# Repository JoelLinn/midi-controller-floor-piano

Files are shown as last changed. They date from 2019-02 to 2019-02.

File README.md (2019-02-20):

# midi-controller-floor-piano
Converts your awful sounding floor piano into a midi keyboard controller you can hook up to your synthesizers.
It uses an ARM NXP LPC1113 MCU which is hopelessly overpowered but still quite cheap.

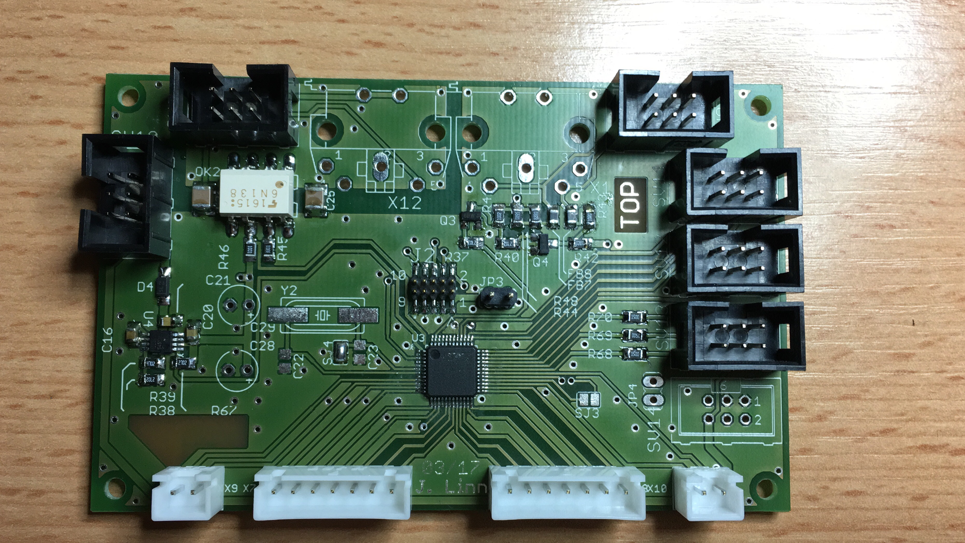
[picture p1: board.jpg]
Image of midi controller board

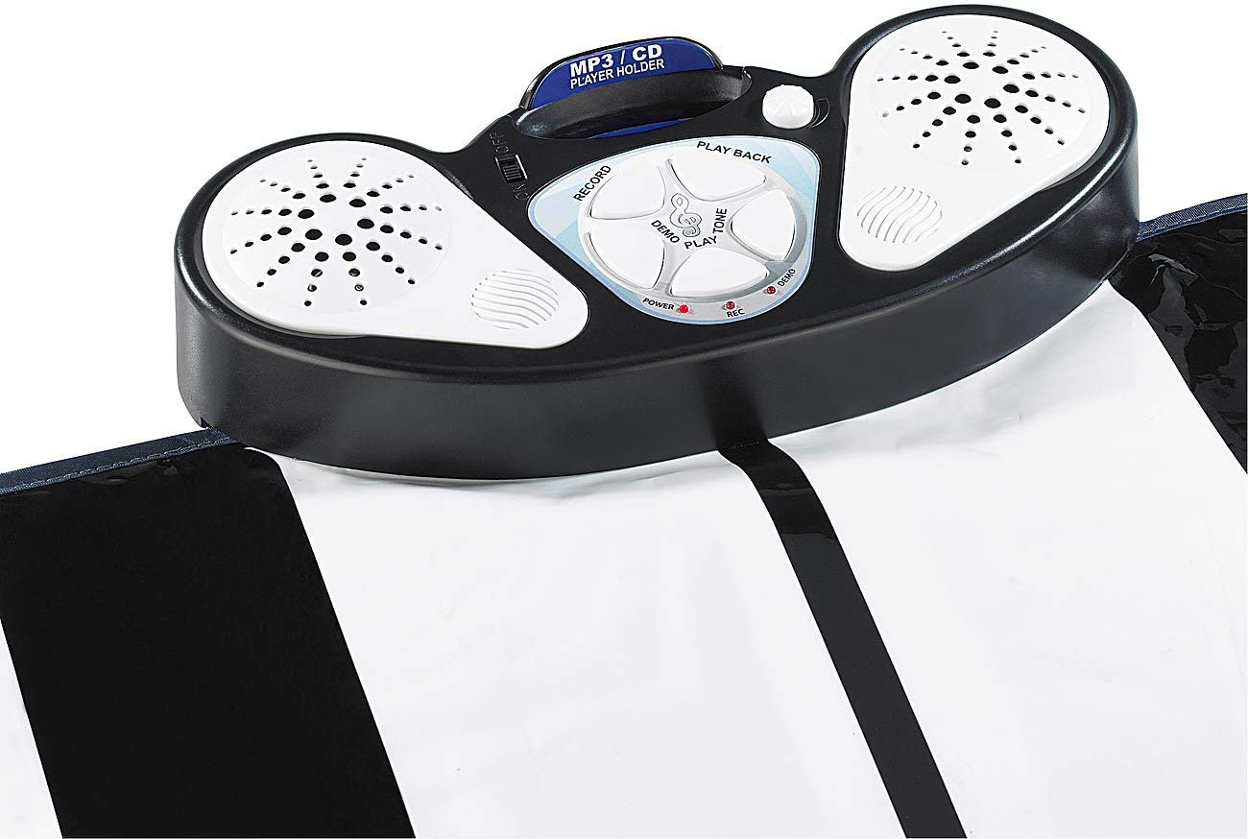
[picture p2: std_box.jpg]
Image of standard controller box


Fits where the stock board belonged and supports the original battery, buttons and leds.
The firmware, although working great, is merely in a POC state so I would prefer to hand it out only on request.

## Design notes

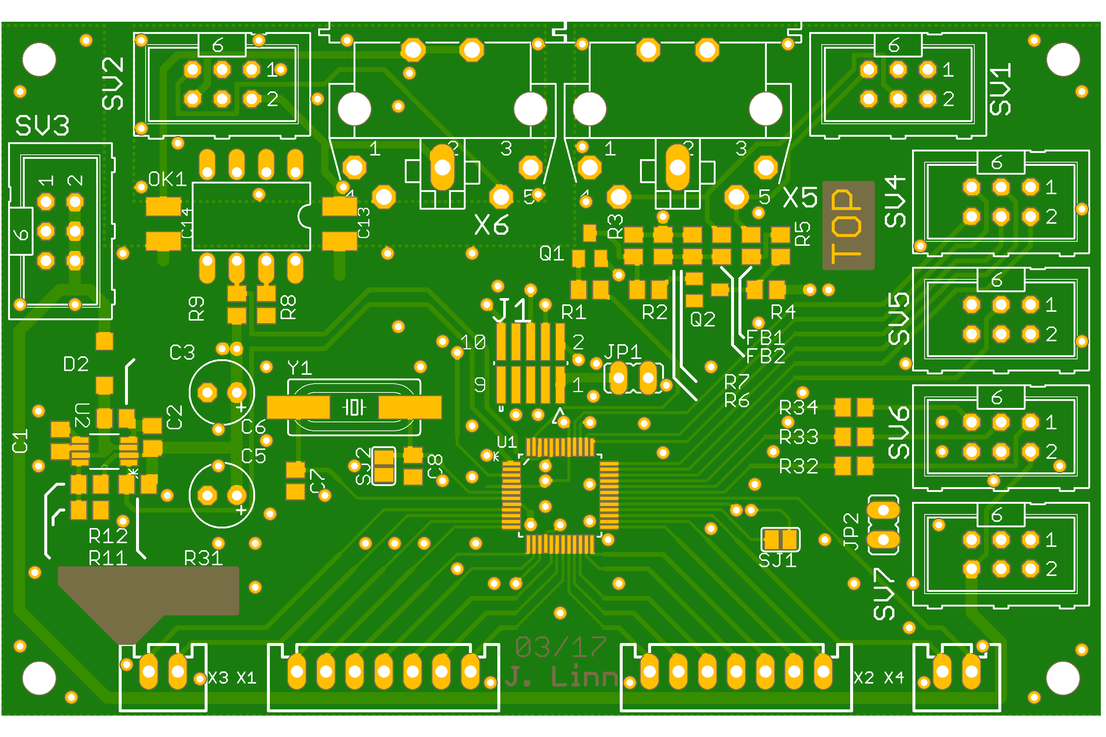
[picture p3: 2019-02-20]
board_top.png

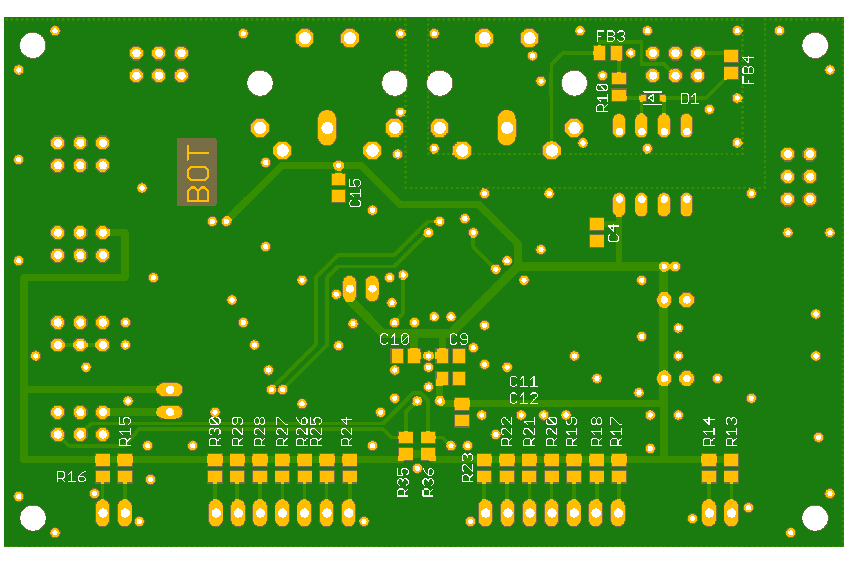
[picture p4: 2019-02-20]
board_bot.png

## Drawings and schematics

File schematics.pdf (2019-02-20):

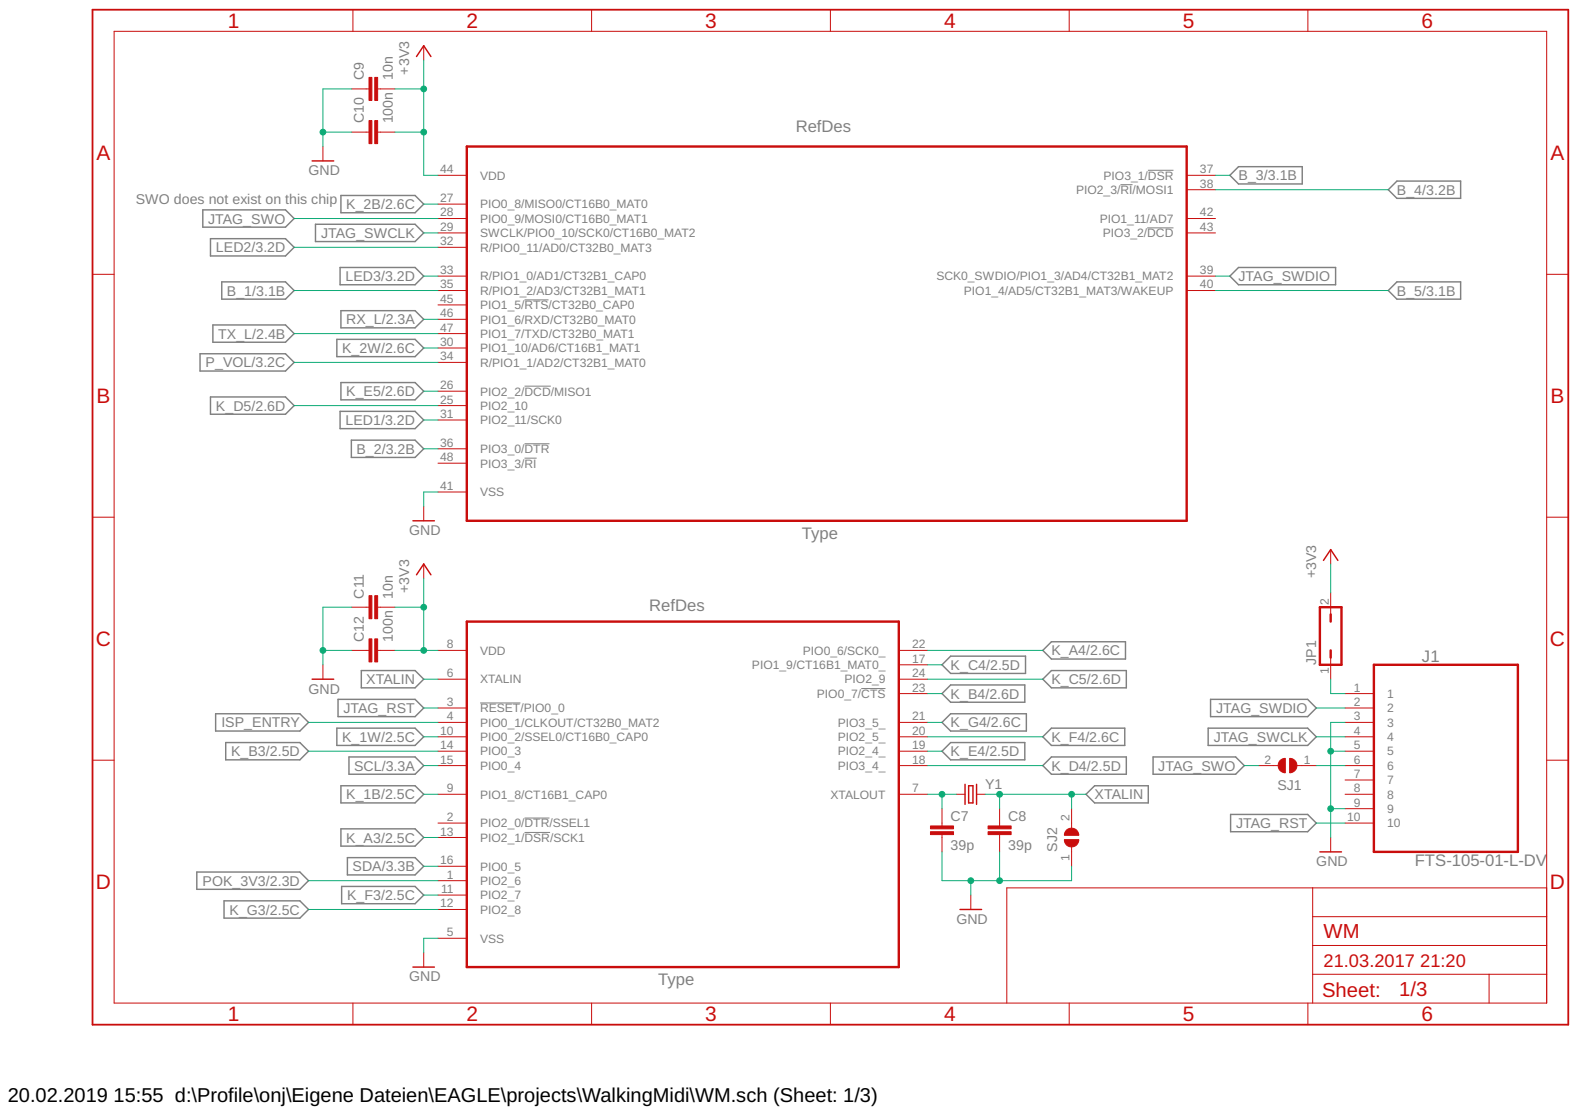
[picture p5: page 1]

SWO does not exist on this chip

20.02.2019 15:55 d:\Profile\onj\Eigene Dateien\EAGLE\projects\WalkingMidi\WM.sch (Sheet: 1/3)

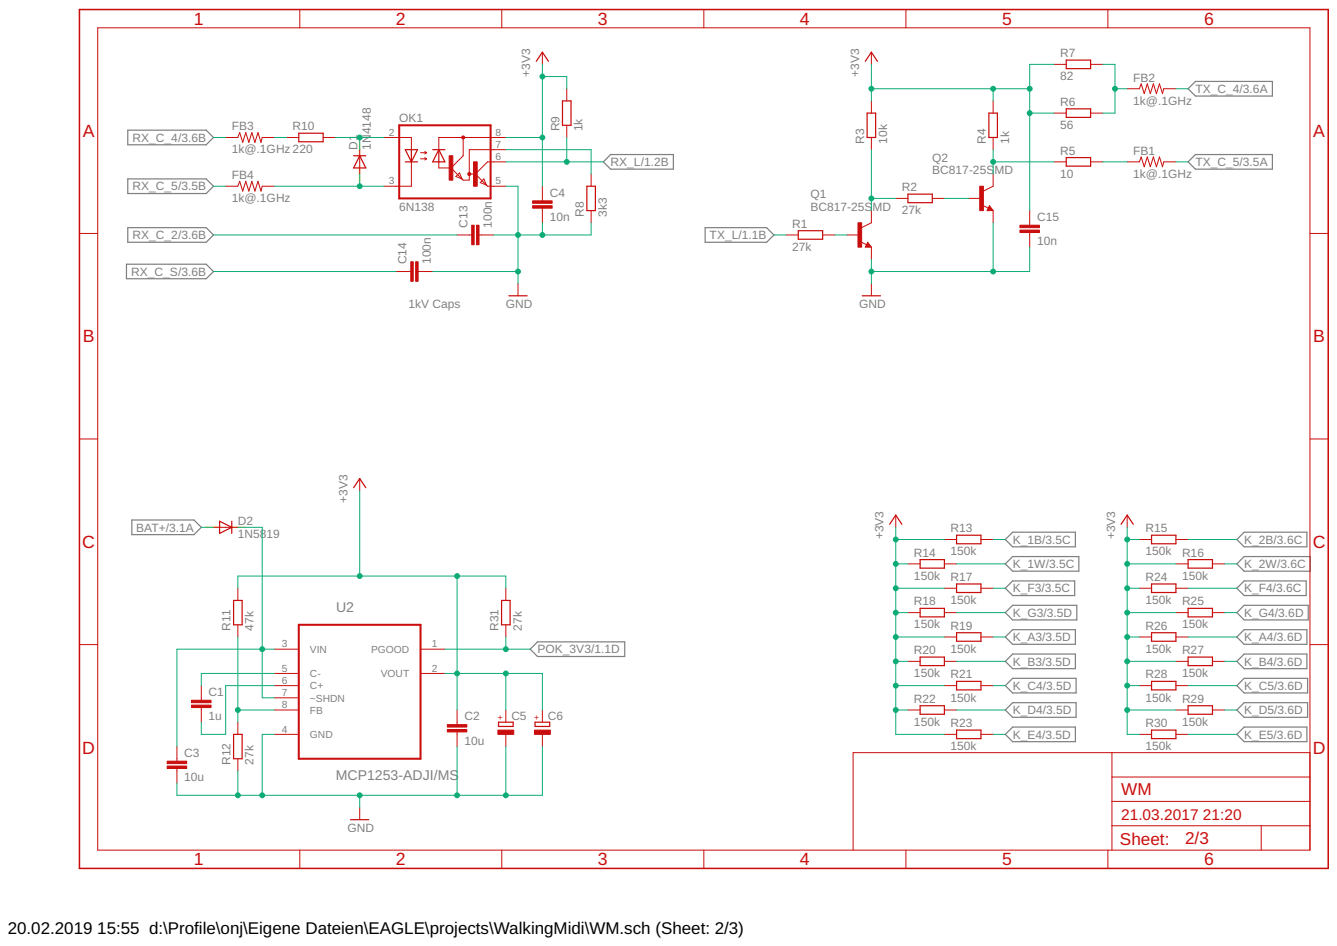
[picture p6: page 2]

20.02.2019 15:55 d:\Profile\onj\Eigene Dateien\EAGLE\projects\WalkingMidi\WM.sch (Sheet: 2/3)

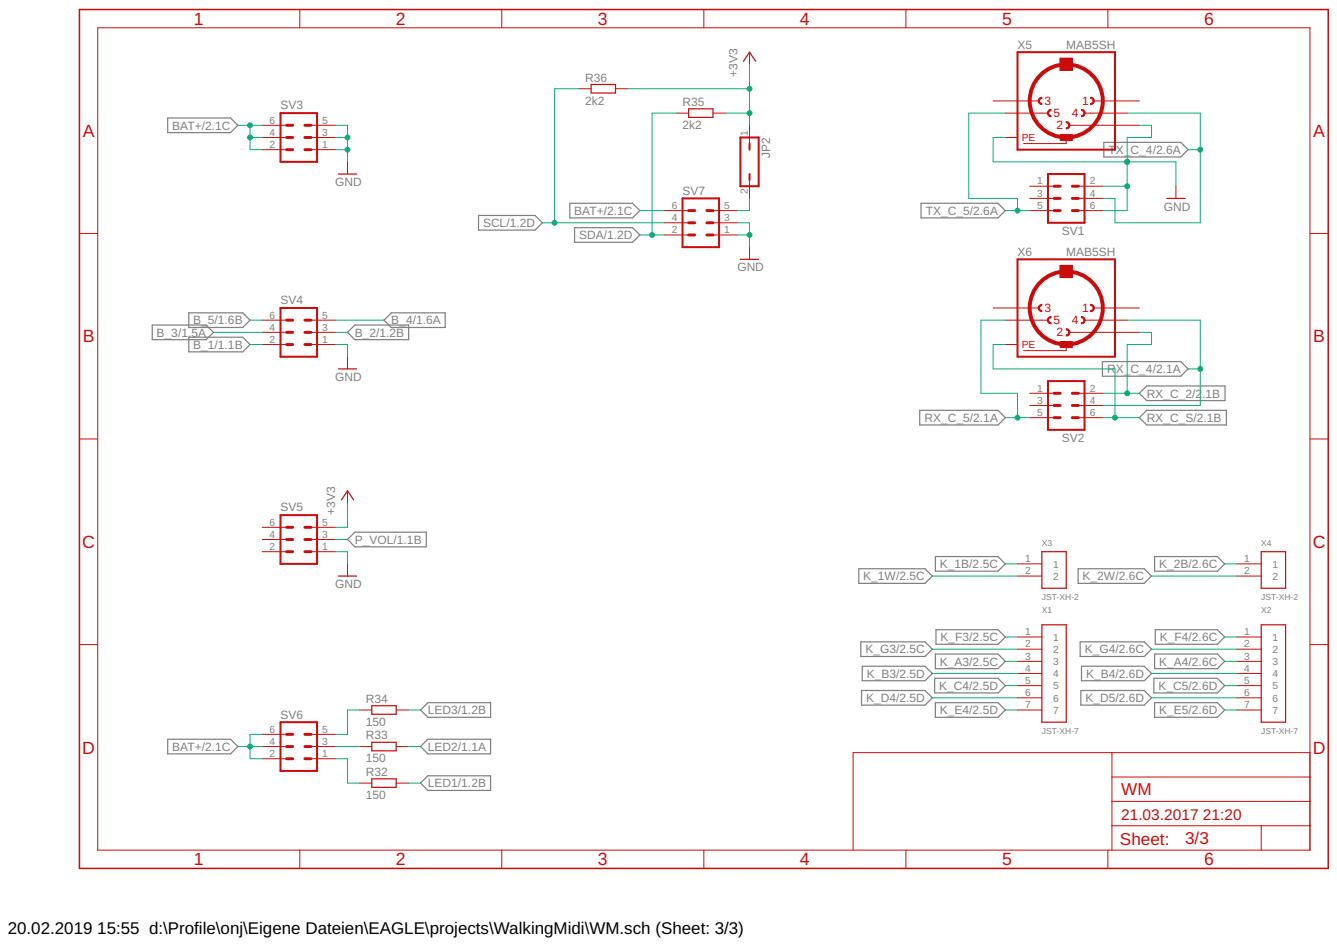
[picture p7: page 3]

20.02.2019 15:55 d:\Profile\onj\Eigene Dateien\EAGLE\projects\WalkingMidi\WM.sch (Sheet: 3/3)

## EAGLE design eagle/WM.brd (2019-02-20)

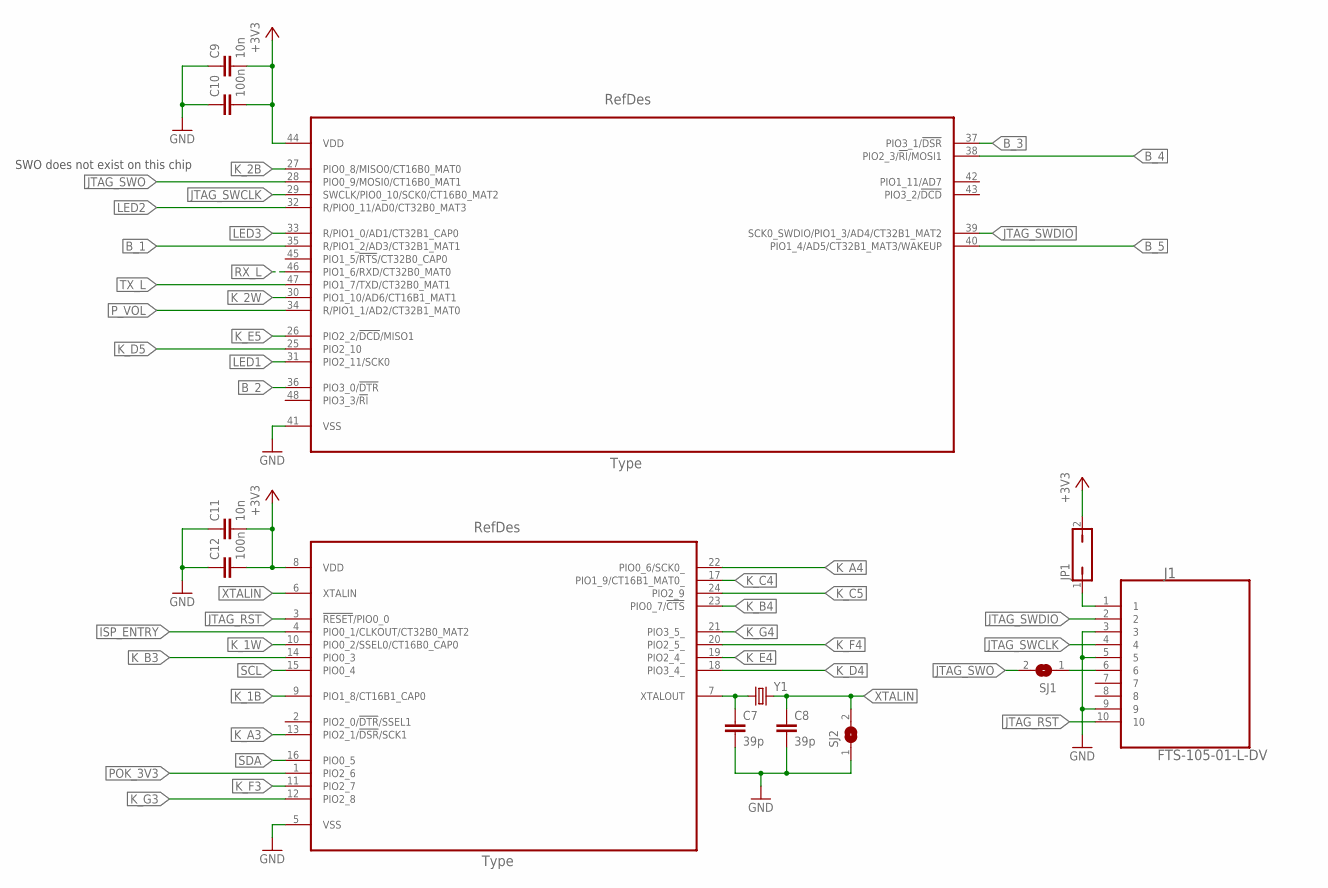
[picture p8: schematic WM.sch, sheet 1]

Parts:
C7, C8: 39p; C0805
C9, C11: 10n; C0805
C10, C12: 100n; C0805
J1: FTS-105-01-L-DV; SAMTEC_FTS-105-01-L-DV
JP1: JP1Q; JP1
SJ1, SJ2: SJ
U1: LPC1113FBD48/302,1; QFP50P900X900X160-48N
Y1: CRYSTALHC49UP; HC49UP

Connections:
+3V3: C9.2, C10.2, C11.2, C12.2, JP1.2, U1.8 (VDD), U1.44 (VDD); also elsewhere on the board
B_1: U1.35 (R/PIO1_2/AD3/CT32B1_MAT1); also elsewhere on the board
B_2: U1.36 (PIO3_0/!DTR!); also elsewhere on the board
B_3: U1.37 (PIO3_1/!DSR!); also elsewhere on the board
B_4: U1.38 (PIO2_3/!RI!/MOSI1); also elsewhere on the board
B_5: U1.40 (PIO1_4/AD5/CT32B1_MAT3/WAKEUP); also elsewhere on the board
GND: C7.2, C8.2, C9.1, C10.1, C11.1, C12.1, J1.3, J1.5, J1.9, SJ2.1, U1.5 (VSS), U1.41 (VSS); also elsewhere on the board
ISP_ENTRY: U1.4 (PIO0_1/CLKOUT/CT32B0_MAT2)
JTAG_RST: J1.10, U1.3 (!RESET!/PIO0_0)
JTAG_SWCLK: J1.4, U1.29 (SWCLK/PIO0_10/SCK0/CT16B0_MAT2)
JTAG_SWDIO: J1.2, U1.39 (SCK0_SWDIO/PIO1_3/AD4/CT32B1_MAT2)
JTAG_SWO: SJ1.2, U1.28 (PIO0_9/MOSI0/CT16B0_MAT1)
K_1B: U1.9 (PIO1_8/CT16B1_CAP0); also elsewhere on the board
K_1W: U1.10 (PIO0_2/SSEL0/CT16B0_CAP0); also elsewhere on the board
K_2B: U1.27 (PIO0_8/MISO0/CT16B0_MAT0); also elsewhere on the board
K_2W: U1.30 (PIO1_10/AD6/CT16B1_MAT1); also elsewhere on the board
K_A3: U1.13 (PIO2_1/!DSR!/SCK1); also elsewhere on the board
K_A4: U1.22 (PIO0_6/SCK0_); also elsewhere on the board
K_B3: U1.14 (PIO0_3); also elsewhere on the board
K_B4: U1.23 (PIO0_7/!CTS!); also elsewhere on the board
K_C4: U1.17 (PIO1_9/CT16B1_MAT0_); also elsewhere on the board
K_C5: U1.24 (PIO2_9); also elsewhere on the board
K_D4: U1.18 (PIO3_4_); also elsewhere on the board
K_D5: U1.25 (PIO2_10); also elsewhere on the board
K_E4: U1.19 (PIO2_4_); also elsewhere on the board
K_E5: U1.26 (PIO2_2/!DCD!/MISO1); also elsewhere on the board
K_F3: U1.11 (PIO2_7); also elsewhere on the board
K_F4: U1.20 (PIO2_5_); also elsewhere on the board
K_G3: U1.12 (PIO2_8); also elsewhere on the board
K_G4: U1.21 (PIO3_5_); also elsewhere on the board
LED1: U1.31 (PIO2_11/SCK0); also elsewhere on the board
LED2: U1.32 (R/PIO0_11/AD0/CT32B0_MAT3); also elsewhere on the board
LED3: U1.33 (R/PIO1_0/AD1/CT32B1_CAP0); also elsewhere on the board
unnamed: C7.1, U1.7 (XTALOUT), Y1.1
unnamed: J1.1, JP1.1
unnamed: J1.6, SJ1.1
POK_3V3: U1.1 (PIO2_6); also elsewhere on the board
P_VOL: U1.34 (R/PIO1_1/AD2/CT32B1_MAT0); also elsewhere on the board
RX_L: U1.46 (PIO1_6/RXD/CT32B0_MAT0); also elsewhere on the board
SCL: U1.15 (PIO0_4); also elsewhere on the board
SDA: U1.16 (PIO0_5); also elsewhere on the board
TX_L: U1.47 (PIO1_7/TXD/CT32B0_MAT1); also elsewhere on the board
XTALIN: C8.1, SJ2.2, U1.6 (XTALIN), Y1.2

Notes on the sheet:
SWO does not exist on this chip

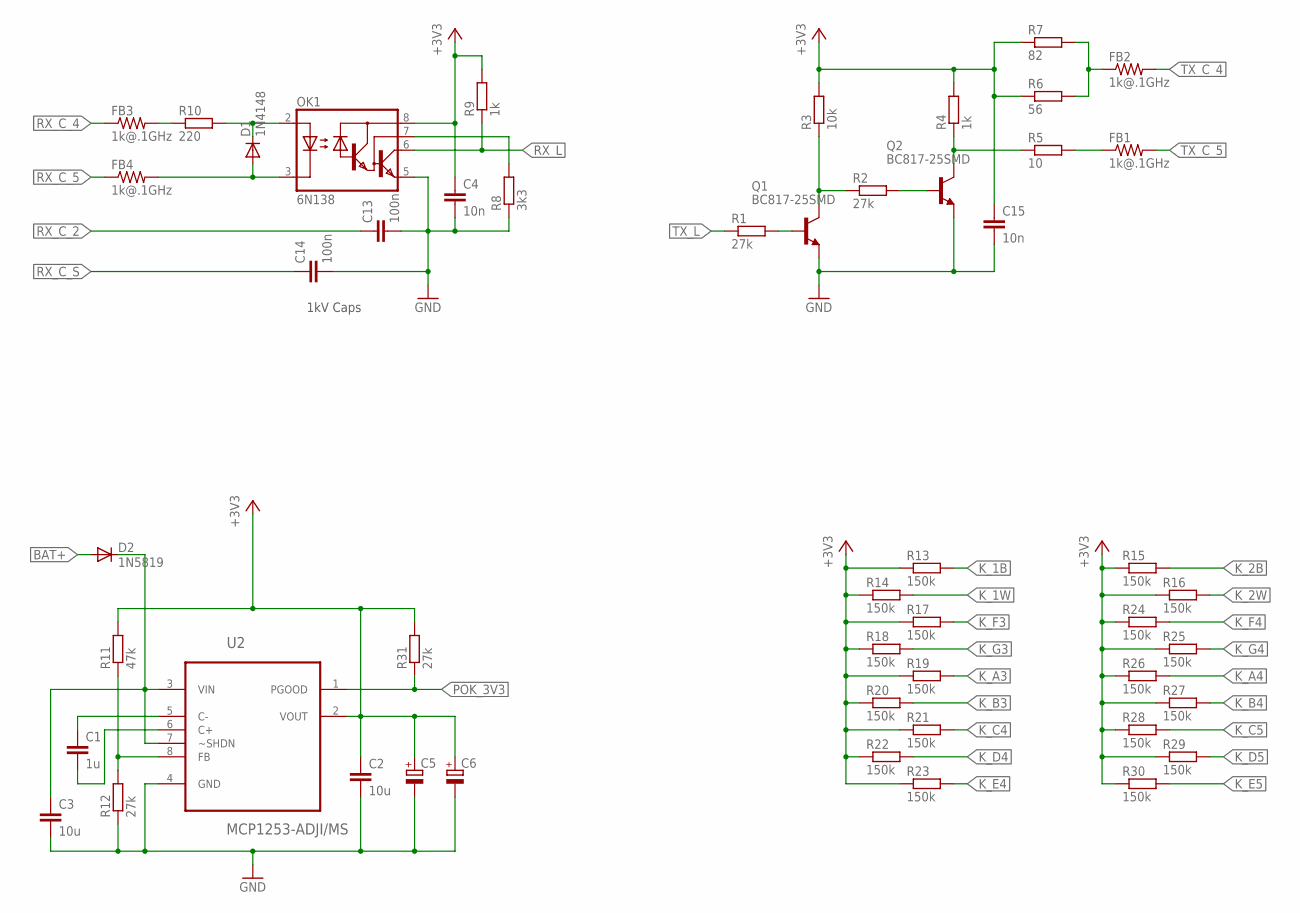
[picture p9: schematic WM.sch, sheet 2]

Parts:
C1: 1u; C0805
C2, C3: 10u; C0805
C4, C15: 10n; C0805
C5, C6: CPOL-EUE2.5-6; E2,5-6
C13, C14: 100n; C1210K
D1: 1N4148; SOD323-R
D2: 1N5819; SOD123
FB1, FB2, FB3, FB4: 1k@.1GHz; R0805
OK1: 6N138; DIL08
Q1, Q2: BC817-25SMD; SOT23-BEC
R1, R2, R12, R31: 27k; R0805
R3: 10k; R0805
R4, R9: 1k; R0805
R5: 10; R0805
R6: 56; R0805
R7: 82; R0805
R8: 3k3; R0805
R10: 220; R0805
R11: 47k; R0805
R13, R14, R15, R16, R17, R18, R19, R20, R21, R22, R23, R24, R25, R26, R27, R28, R29, R30: 150k; R0805
U2: MCP1253-ADJI/MS; SOP65P490X118-8N

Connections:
+3V3: C2.1, C4.1, C5.+, C6.+, C15.1, OK1.8 (VCC), R3.2, R4.2, R6.1, R7.1, R9.2, R11.2, R13.1, R14.1, R15.1, R16.1, R17.1, R18.1, R19.1, R20.1, R21.1, R22.1, R23.1, R24.1, R25.1, R26.1, R27.1, R28.1, R29.1, R30.1, R31.2, U2.2 (VOUT); also elsewhere on the board
BAT+: D2.A; also elsewhere on the board
GND: C2.2, C3.2, C4.2, C5.-, C6.-, C13.2, C14.2, C15.2, OK1.5 (GND), Q1.E, Q2.E, R8.1, R12.1, U2.4 (GND); also elsewhere on the board
K_1B: R13.2; also elsewhere on the board
K_1W: R14.2; also elsewhere on the board
K_2B: R15.2; also elsewhere on the board
K_2W: R16.2; also elsewhere on the board
K_A3: R19.2; also elsewhere on the board
K_A4: R26.2; also elsewhere on the board
K_B3: R20.2; also elsewhere on the board
K_B4: R27.2; also elsewhere on the board
K_C4: R21.2; also elsewhere on the board
K_C5: R28.2; also elsewhere on the board
K_D4: R22.2; also elsewhere on the board
K_D5: R29.2; also elsewhere on the board
K_E4: R23.2; also elsewhere on the board
K_E5: R30.2; also elsewhere on the board
K_F3: R17.2; also elsewhere on the board
K_F4: R24.2; also elsewhere on the board
K_G3: R18.2; also elsewhere on the board
K_G4: R25.2; also elsewhere on the board
unnamed: Q1.B, R1.2
unnamed: Q1.C, R2.1, R3.1
unnamed: Q2.B, R2.2
unnamed: Q2.C, R4.1, R5.1
unnamed: OK1.7 (VB), R8.2
unnamed: C1.1, U2.5 (C-)
unnamed: D1.C, OK1.2 (A), R10.2
unnamed: C1.2, U2.6 (C+)
unnamed: R11.1, R12.2, U2.8 (FB)
unnamed: FB3.2, R10.1
unnamed: D1.A, FB4.2, OK1.3 (C)
unnamed: FB1.1, R5.2
POK_3V3: R31.1, U2.1 (PGOOD); also elsewhere on the board
RX_C_2: C13.1; also elsewhere on the board
RX_C_4: FB3.1; also elsewhere on the board
RX_C_5: FB4.1; also elsewhere on the board
RX_C_S: C14.1; also elsewhere on the board
RX_L: OK1.6 (VO), R9.1; also elsewhere on the board
TX_C_4: FB2.2; also elsewhere on the board
TX_C_5: FB1.2; also elsewhere on the board
TX_H_H: FB2.1, R6.2, R7.2
TX_L: R1.1; also elsewhere on the board
UNREG+: C3.1, D2.C, U2.3 (VIN), U2.7 (~SHDN)

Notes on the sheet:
1kV Caps

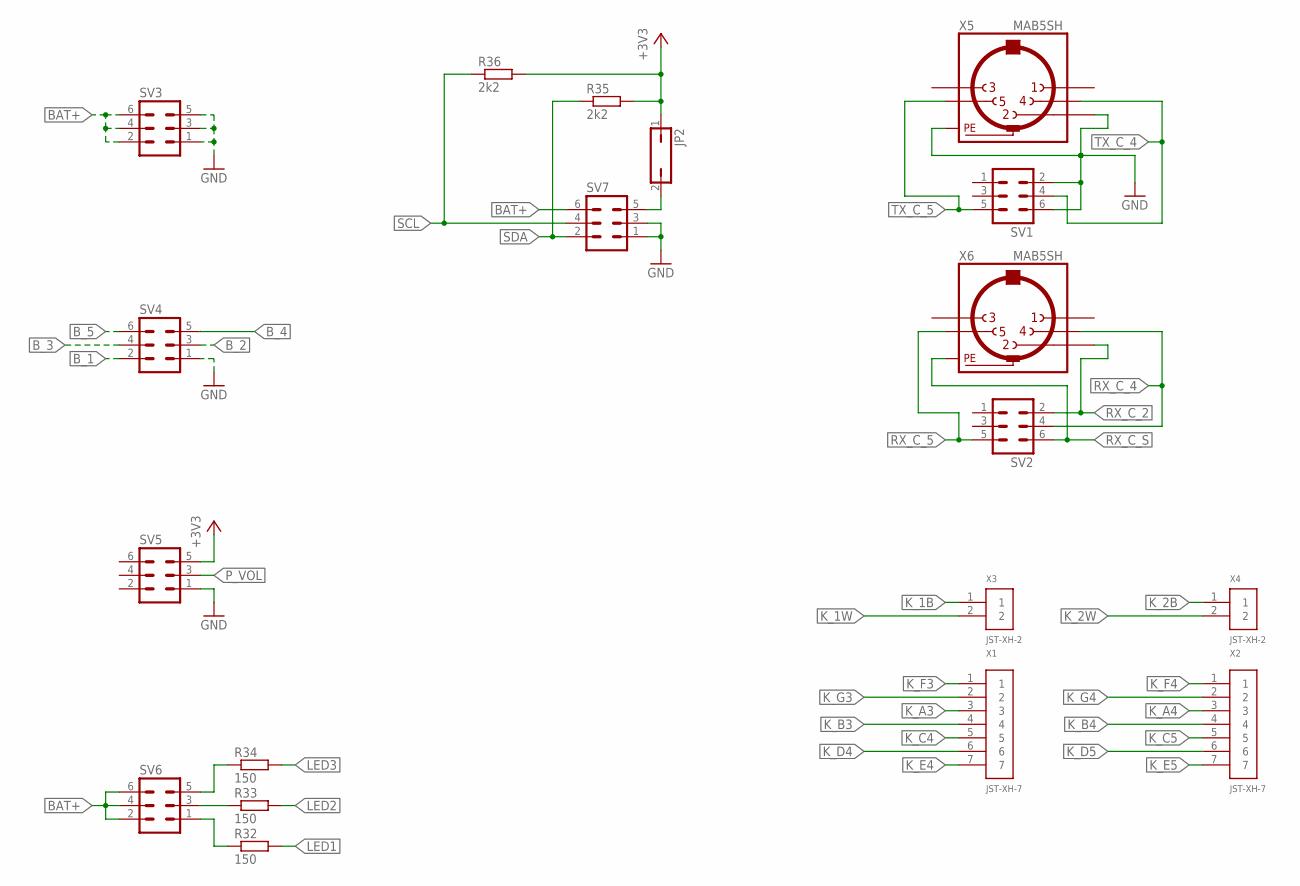
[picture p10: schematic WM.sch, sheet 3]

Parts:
JP2: JP1Q; JP1
R32, R33, R34: 150; R0805
R35, R36: 2k2; R0805
SV1, SV2, SV3, SV4, SV5, SV6, SV7: ML6
X1, X2: JST-XH-7
X3, X4: JST-XH-2
X5, X6: MAB5SH

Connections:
+3V3: JP2.1, R35.2, R36.2, SV5.5; also elsewhere on the board
BAT+: SV3.2, SV3.4, SV3.6, SV6.2, SV6.4, SV6.6, SV7.6; also elsewhere on the board
B_1: SV4.2; also elsewhere on the board
B_2: SV4.3; also elsewhere on the board
B_3: SV4.4; also elsewhere on the board
B_4: SV4.5; also elsewhere on the board
B_5: SV4.6; also elsewhere on the board
GND: SV1.2, SV1.6, SV3.1, SV3.3, SV3.5, SV4.1, SV5.1, SV7.1, SV7.3, X5.2, X5.PE, X5.PE@ (PE); also elsewhere on the board
K_1B: X3.1; also elsewhere on the board
K_1W: X3.2; also elsewhere on the board
K_2B: X4.1; also elsewhere on the board
K_2W: X4.2; also elsewhere on the board
K_A3: X1.3; also elsewhere on the board
K_A4: X2.3; also elsewhere on the board
K_B3: X1.4; also elsewhere on the board
K_B4: X2.4; also elsewhere on the board
K_C4: X1.5; also elsewhere on the board
K_C5: X2.5; also elsewhere on the board
K_D4: X1.6; also elsewhere on the board
K_D5: X2.6; also elsewhere on the board
K_E4: X1.7; also elsewhere on the board
K_E5: X2.7; also elsewhere on the board
K_F3: X1.1; also elsewhere on the board
K_F4: X2.1; also elsewhere on the board
K_G3: X1.2; also elsewhere on the board
K_G4: X2.2; also elsewhere on the board
LED1: R32.2; also elsewhere on the board
LED2: R33.2; also elsewhere on the board
LED3: R34.2; also elsewhere on the board
unnamed: R34.1, SV6.5
unnamed: R33.1, SV6.3
unnamed: R32.1, SV6.1
unnamed: JP2.2, SV7.5
P_VOL: SV5.3; also elsewhere on the board
RX_C_2: SV2.2, X6.2; also elsewhere on the board
RX_C_4: SV2.4, X6.4; also elsewhere on the board
RX_C_5: SV2.5, X6.5; also elsewhere on the board
RX_C_S: SV2.6, X6.PE, X6.PE@ (PE); also elsewhere on the board
SCL: R36.1, SV7.4; also elsewhere on the board
SDA: R35.1, SV7.2; also elsewhere on the board
TX_C_4: SV1.4, X5.4; also elsewhere on the board
TX_C_5: SV1.5, X5.5; also elsewhere on the board

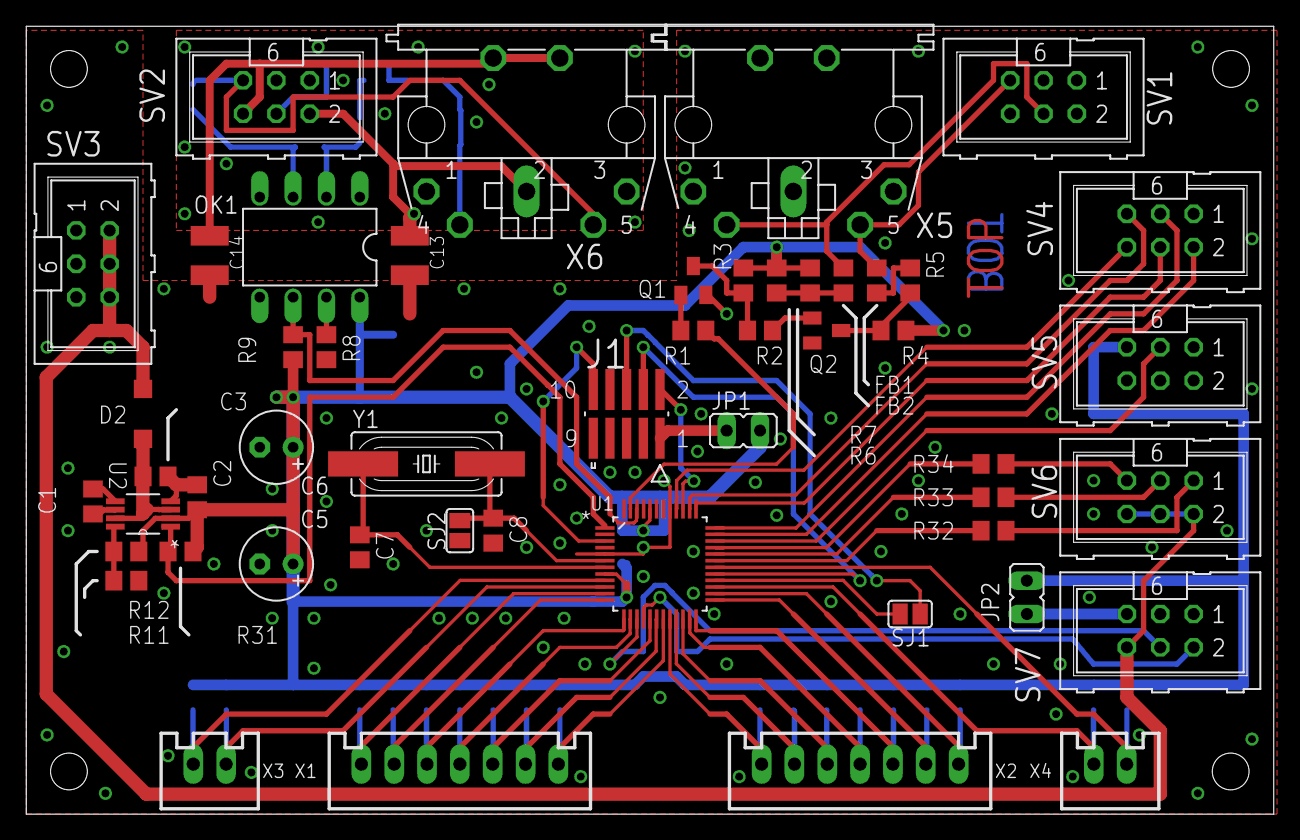
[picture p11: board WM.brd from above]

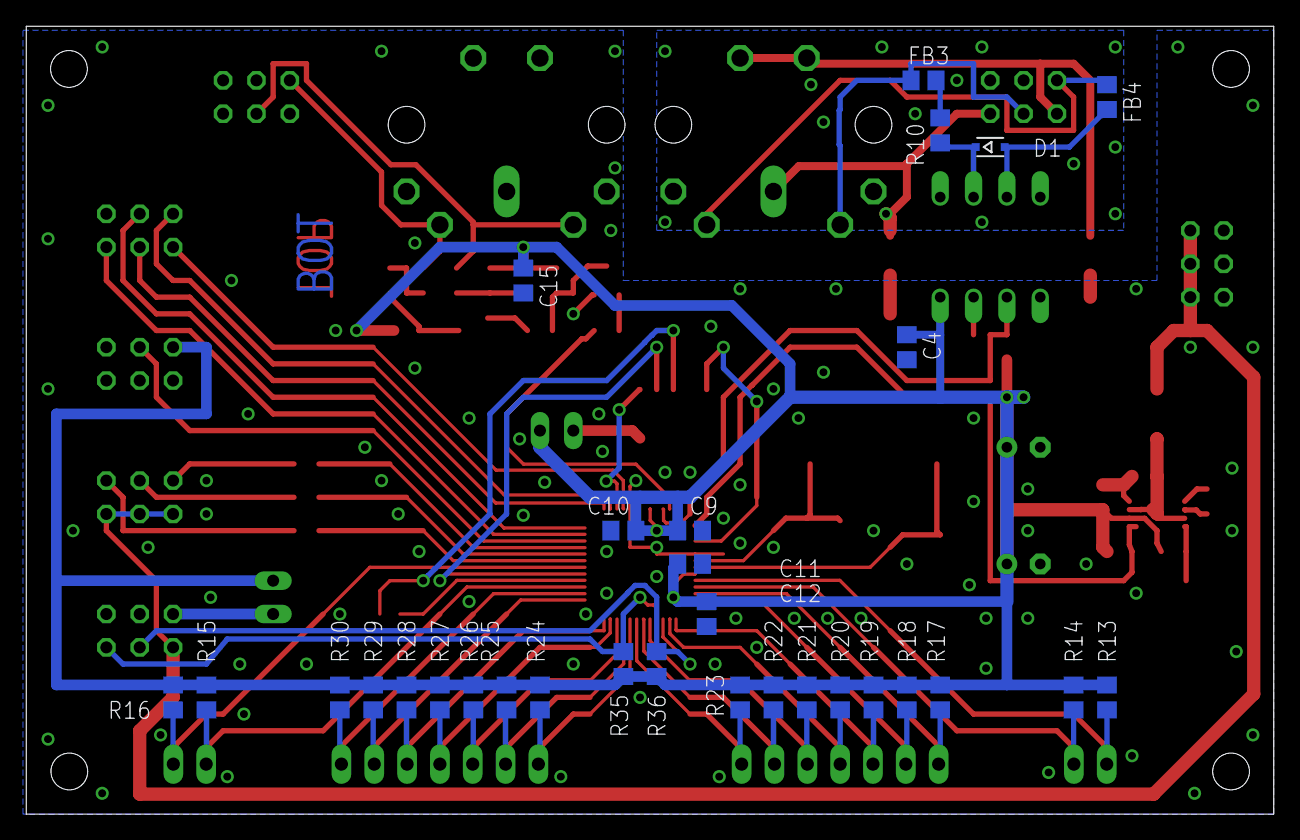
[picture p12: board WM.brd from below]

Board: 2 copper layers, 95.0 x 60.0 mm, 81 parts (30 on the bottom side), 67 nets.
